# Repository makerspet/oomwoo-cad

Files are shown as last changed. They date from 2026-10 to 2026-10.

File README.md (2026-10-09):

<div align="center">

# OOMWOO One CAD

*Open-source robot vacuum you build yourself.*

3D CAD · STEP · 3D printable · Chassis · Mounts · Open hardware





</div>

DIY build instructions [will be posted here](https://makerspet.com/blog/oomwoo-vacuum-build-instructions/). Please visit project home [OOMWOO](https://github.com/makerspet/oomwoo).

## Repository layout

- [`designs/`](designs) - product designs: one folder per product, one subfolder per variant ([how it is organized](designs/README.md)). [`designs/one/stock/`](designs/one/stock) is the OOMWOO One itself.
- [`lib/`](lib) - off-the-shelf parts, 3D scanned or sourced as STEP
- [`docs/`](docs) - spec and design references

## Active work in progress

oomwoo_base_sept_7

side_brush_reverse_engineered

vacuum_assembly_reverse_engineered

## Dock concept

oomwoo_dock_concept

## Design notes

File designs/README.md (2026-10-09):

# Designs

One folder per product, and inside it one folder per variant.

```
designs/
  one/              OOMWOO One robot vacuum
    stock/          the standard OOMWOO One: Fusion 360 sources, STEP exports
    agentic/        AI-generated design experiments, kept for reference - not the design
```

## Why variants

A mod rarely touches one part. A top plate that gives a cat a ride, say, changes the
enclosure, the bumper and the way they mount to the base. A variant folder holds the
**whole** modified design, so anyone can open it and build it in one go instead of
piecing changed parts together from several places.

## Adding a variant

1. Copy `stock/` (or the variant you are starting from) to a new folder named after
   your mod, for example `designs/one/cat-rider/`.
2. Change what you need.
3. Add a `README.md` saying what changed and why, with a picture if you have one.
4. Open a pull request.

Off-the-shelf parts - motors, sensors, brushes, the 3D-scanned STEP models - live in
[`lib/`](../lib), shared by every product and variant.

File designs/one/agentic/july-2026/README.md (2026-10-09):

# Agentic CAD experiment (July 2026)

An early experiment for OOMWOO One: we tried an agentic CAD pipeline to see how far it could get. An LLM-driven multi-agent workflow was asked to turn the project spec and a set of component STEP files into a complete, closed, 3D-printable robot vacuum, written entirely as code-CAD.

This folder is a snapshot of that experiment, shared as-is in the build-in-public spirit of the project.

> **This is not the OOMWOO One design.** It is unreviewed pipeline output from a single revision ("RV02") and has known design errors, listed below. The actual design work lives in [`designs/one/stock/`](../../stock) and [`lib/`](../../../../lib).

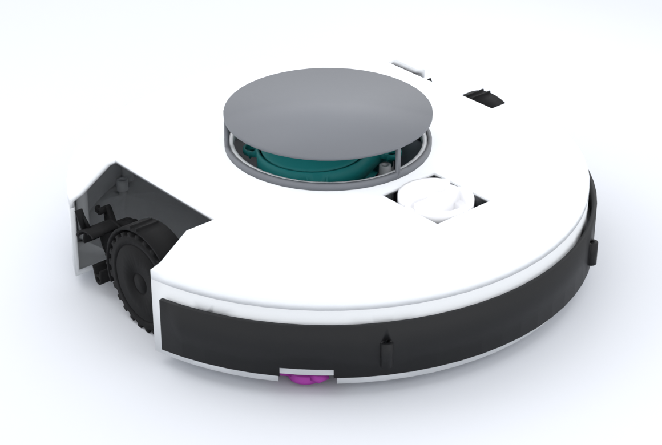
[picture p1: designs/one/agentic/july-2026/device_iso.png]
RV02 closed device, as rendered by the pipeline


## Contents

| File | What it is |
|---|---|
| [`OOMWOO_Device_RV02_Report.pdf`](OOMWOO_Device_RV02_Report.pdf) | 9-page report written by the pipeline: layout, enclosure, verification numbers, print and assembly notes, limitations |
| [`device_full.step`](device_full.step) | Full assembly of that revision: 15 placed components plus the generated base, cover, LiDAR turret cap, bumper, dustbin and battery door (15.6 MB) |
| `device_iso.png` | Render of the closed device, taken from the report |
| `device_full.png` | The same revision with the cover off, showing the component packing |

## How it was made

- **Tooling:** [Claude Code](https://claude.com/claude-code) with Claude Fable 5 orchestrating a multi-agent loop: a designer agent wrote the geometry, and a separate QA agent re-measured the built solids before each phase was accepted.
- **CAD kernel:** [build123d](https://github.com/gumyr/build123d) 0.10.0 on OpenCascade. All geometry is Python code; no GUI CAD was used.
- **Inputs:** the project spec, the LiDAR and compute-module STEP files from [`lib/`](../../../../lib), and stand-in geometry from an older robot vacuum for the parts that had not been 3D-scanned yet.
- **When:** 23-25 July 2026. `device_full.step` is the direct pipeline export of 24 July; nothing in it was edited by hand.

## What worked

- Importing real component STEP files into one coordinate frame and packing 15 of them inside a Ø355 mm envelope with zero boolean interference.
- Generating a base, domed cover, turret cap and front bumper around those components, with numeric gates (interference, clearances, parting-line gap, bumper travel, overall height) checked on the final solids rather than on the generator's intent.
- Swapping one component for another (for example one LiDAR for a different model) with a one-line registry change and regenerating the chassis around it.
- Producing the report, sections and renders automatically from the same model.

## What did not

Every gate the pipeline set for itself passed, and the report says so. What it had no gate for was design intent: which way up a part goes, and whether the layout makes sense as a robot vacuum. Human review of this revision found:

- Side brush mounted sideways and upside down; caster wheel upside down; rubber push-button cover upside down.
- LiDAR puck off-centre, inside an oversized turret.
- Suction fan on the opposite side of the robot from the main brush.
- A round port in the floor with no airflow path designed around it.
- Bumper attached outside the cylindrical body, with its mounts exposed on the exterior.
- Battery-compartment door smaller than the battery, and the battery itself a stand-in rather than the Roborock pack in the BOM.
- No mop.

The takeaway at the time: the pipeline was dependable at what can be measured (fit, clearance, interference, print-bed limits) and unreliable at what has to be understood (orientation, function, layout). Output like this needs a person to review it before it is treated as a design.

## Credits and license

Experiment by Muhammed Ikbal Arikan ([@mikbalarikan](https://github.com/mikbalarikan)) as part of the OOMWOO One CAD work. Released under the repository's [Apache-2.0 license](../../../../LICENSE).

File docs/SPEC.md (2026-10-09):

OOMWOO One open-source vacuum robot spec

A brain-dump with some explanations. First of all, there are 3 living documents

- BOM.md https://github.com/makerspet/oomwoo/blob/main/BOM.md
- Companion article https://makerspet.com/blog/how-to-source-bom-for-oomwoo-open-source-vacuum-robot/
- 3D design spec https://github.com/makerspet/oomwoo-one-cad/blob/main/docs/SPEC.md

All 3D CAD design files live in this repo https://github.com/makerspet/oomwoo-one-cad

Let me go over each component and explain the thinking about it. Please let me know any comments/questions.

I will list the "recommended selection" as well as "backup alternatives".

- "Drive wheel assembly pair". Recommended - reuse Roborock S5 Max wheels because they are abundant in the aftermarket https://makerspet.com/blog/how-to-source-bom-for-oomwoo-open-source-vacuum-robot/#driving-wheels There is a backup alternative - Roborock S5 (non-Max) wheels. These are also abundant, but older. So, don't use those, lets stick with Roborock S5 Max.
- "Caster wheel". Recommended - caster wheel off iRobot Roomba I3/4/6/8, J7/Plus J7 E5/6 500 600 700 800 900 series. It appears to be the most abundant in the aftermarket. iRobot has used the same caster part using in all those models over years. Backup alternatives - plenty available off-the-shelf on AliExpress; or 3D print using TPU.
- "Suction fan". Recommended - BL24131616 10kPa. Recommended for 2nd vacuum version - 36 kPa from Roborock Saros 20, . Backup alternatives - fans with lower suction. Why 10kPa - modern vacuums use increasingly stronger suction. Old vacuums use mere 2-2.5kPa. Users want to see bigger kPa suction.
- "Main brush". Recommended - "Anti-tangle split single roller, rubber and bristles" for Roborock Saros. Users *strongly* want no tangling at all. This roller type seems one of the best - but *I may be wrong*. Another roller that appears to be great is "Anti-tangle hair-cutting dual roller, rubber and bristles", sold as replacement for Dreame vacuums. Please read about roller choices here https://makerspet.com/blog/how-to-source-bom-for-oomwoo-open-source-vacuum-robot/#main-brush Another option is 2 rollers, but having 2 rollers (I assume) will complicate your CAD design. So single (or single split?) roller seems best for 1st vacuum version. The 1st vacuum version's name is OOMWOO One.
- "Battery pack + BMS". Required - the standard Roborock battery. Roborock has been using it over many years and many models. It comes with built-in protection and thermistor. No obvious alternatives.
- "2D LiDAR". Recommended - "PCB mark X-WPFTB-V2.6.2, possibly Camsense". However, there are many alternatives. Some users own different LiDARs - and want to reuse them. So, we should let users pick their LiDAR - by 3D printing a custom mounting bracket.
- "Compute Module". Required - Raspberry Pi CM4 or CM5. CM4 and CM5 have identical dimensions.
- "I/O board". Required - custom-designed PCB https://github.com/makerspet/oomwoo-io-board. The I/O board will have all motor/sensor connectors, driver ICs. The "Compute Module" will plug into the I/O board. The I/O board shape/dimensions is *not* set - it will be decided based on your CAD design.
- "Cliff sensors". Required - "cliff sensor + bumper switches bundle" iRobot Roomba 500 600 700 800 528 552 564 595 560 570 610 615 620 625 630 650 off-the-shelf, abundant in the aftermarket. The "bundle" includes 4 IR cliff sensors and 2 bumper switch assemblies. Backup alternatives - if this bundle doesn't work for you, let me know, I will suggest alternatives. Please note - some vacuums have 4 IR cliff sensors, while others have 6. The typical 4-sensor placement is (1) around the caster wheel (in the front) and in front of each driving wheel. 6-sensor vacuums add one sensor just behind each driving wheel. I've noticed some vacuums have 5 sensors (only one driving wheel has 2 cliff sensors). Generally, I'd like to have 6 cliff sensors, but 6-sensor bundles are harder to find/purchase.
- "Bumper switches". Required - please use the iRobot bundle. If you find a problem using these - let me know.
- "Main brush motor, gearbox". Required - let's use one off Roborock S5 because it is abundant. However, this assembly fits Roborock brushes with bristles (which tangle hair badly). So, you may need to design some sort of adapter to accommodate tangle-free brushes. Backup alternatives - we can buy the DC motor and 3D print gears using an SLA resin printer. But I'd like to avoid this additional complexity if possible. FYI, commercial vacuums use RS390 and RS395 DC motors.
- "Side brush". Recommended - "2-arm curved" side brush from Roborock Saros. It seems better at anti-tangling (but I haven't checked). Backup alternatives - older Roborock side brushes or Dreame side brushes.
- "Side brush motor". Recommended - only one side brush, extendable, from Roborock Qrevo https://www.alibaba.com/product-detail/Roborock-Telescopic-Robotic-Arm-Side-Brush_1601598853246.html Backup alternatives - if the recommended one doesn't work for you, let me know, I will check Dreame X40 and Dreame X50 extendable side brush assemblies.
- "Wall sensor". Required - two little custom-designed PCB (one left, one right). These sensors (1) detect IR signal from the dock (2) detect wall (in a crude way). Backup alternative - a Roborock wall sensor assembly is available on AliExpress, but not abundant.
- "Dock homing sensor". Required - a little custom-designed PCB with two IR sensors, in vacuum rear front. Backup alternatives - let me know if there is a problem and I will check.
- "Carpet sensor". Required - ultrasonic 300kHz material sensor, fixed 30mm distance above floor. This model for your initial CAD design https://www.aliexpress.us/item/3256808845934210.html and this model for volume https://htwsensor.en.made-in-china.com/product/jARpDPKoaxVz/China-300kHz-Carpet-Material-Recognition-Sensor-for-Robotic-Vacuum-Cleaner-Ultraosinc-Sensor-Transducer.h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 .
- "Charging contacts" (on the robot). Recommended - DIY using a nickel-plated steel strip (purchased on AliExpress). Located in the robot's rear around the homing IR sensor PCB. No springs. Strip width/length - up to you. AliExpress has 10-12mm. Each contact (positive, ground) connects to a PCB connector cable. The contact-to-wire connection could be accomplished by designing a tiny 3D printed "terminal'. Have a machine screw pressing the (stripped) wire against the strip.
- "Mop motor assembly". Recommended - 2 rotary/disk mops. One static, one extendable. Use Roborock Qrevo FlexiArm https://www.alibaba.com/product-detail/Mop-Deceleration-Motor-Retractable-Mopping-Module_1601599652498.html Backup alternatives - if the Roborock Qrevo doesn't work for you, I can search Chinese ODM making Dreame MopExtend.
- "Obstacle avoidance camera". Recommended - 1x front-facing OV5647 with a 16-pin flexible cable, ~130 degree FOV. Backup alternatives - none that are cheap.
- Bagless vs bag dock. Recommendation: bagless. Why? Multiple users requested bagless; no-one asked for bags. Also, no consumable bag purchase/cost. The dock's dust bin can be 3D printed. However, bagged is easier to engineer. Bagless needs reliable separation (a working cyclone + washable filter). Designing a good cyclone is important. A poor one sends fine dust straight to the filter, clogs the filter, and suction dies.
Auto-empty design. Recommendation: bottom extraction (Roborock style). Why? This is what my Claude says:
- side brush with extensible arm assembly - expensive, hard to find retail. Roborock uses lots of gears; the brush DC motor both actuates the brush and the arm. Design from scratch using a little timing belt, aluminum timing pulleys and a geared DC motor (metal gearbox comes with the motor). 3D-print the assembly enclosure This avoids having to 3D print gears and keeps the build inexpensive.

=== Claude =====================================

1. Gravity is on your side. Dust settles to the bottom of the bin, and bottom extraction pulls it downward into the dock bin. A dedicated side/rear vent higher on the bin fights gravity — you're asking the fan to lift settled dust before it can carry it out.
2. Simplest robot-side port: one flap. You add a single spring/gravity trap door on the bin bottom — no second sealed opening in the bin. A dedicated vent means a second aperture you must seal against leaks during every vacuuming run.
3. Flat, forgiving dock mating. The dock side is just a gasketed hole in the base plate; the robot parks over it. Flat-plate-to-flat-plate tolerates alignment error far better than threading a nozzle into a port (which a dedicated vent requires). Your ramp/alcove already gets the robot "close enough," and a broad base port forgives the rest — same philosophy as oversizing the charging pads.
4. Proven and measurable. It's the dominant industry design, so you can study/measure a real Roborock dock to de-risk the printed geometry.
5. It decouples from your crowded rear. Your rear is already busy — vertical contacts + mop wash tray (back-in docking). Putting auto-empty on the underside keeps it spatially separate from that cluster.

The hard part is the same for both: the valve + the airflow path

Whichever port you choose, the real engineering is the flap valve and the makeup-air path, not the port location:

- The flap must do two contradictory things: seal tightly during vacuuming (so the robot's own fan doesn't lose suction through the auto-empty port) yet open freely under the dock's airflow. Bottom extraction makes this natural — the dock's downward suction pulls an inward/downward flap open, and spring + gravity reseat it. A high side/rear port needs a more deliberate valve.
- You must give the emptying airflow a makeup-air inlet, or the dock fan just pulls a vacuum against a sealed bin and moves nothing. The clean trick (and what Roborock does): let the dock's suction draw makeup air in through the robot's own intake mouth — which is right there at the bottom — so air sweeps through the bin and out the bottom port, entraining settled dust on the way. Design the bin so that emptying airflow traverses the whole bin volume rather than short-circuiting between two nearby openings. This is the single thing that determines whether auto-empty actually evacuates dust vs. just whistling.

Why not the dedicated bin vent

- Its only real advantage is a seal that's higher and away from floor-level dust. That's outweighed by: a second aperture to seal, a nozzle-to-port mating that's alignment-fussy, fighting gravity, and more total seals — all worse for a printed part where every seam is a potential leak. Not worth it.

Two build-specific notes

- Bagless synergy: bottom extraction drops dust straight down into the dock's printed bin sitting in the base — exactly what you want for the bagless, printed-container design you chose. Gravity does half the work of separating debris before the dock cyclone/filter even acts.
- Since the robot backs in rear-first (mop-dock orientation), position the dock base's suction hole under wherever the robot's bottom bin-port ends up in the docked position — likely forward of the mop/contact cluster. This is part of the same frozen dock interface as the contacts and the beacon, across all three tiers.

So: pull from underneath through a single bottom trap-door, let makeup air come in via the robot's intake so the flow sweeps the bin, and drop it into the printed dock bin by gravity. The dedicated-vent approach adds sealing complexity for a benefit you don't need.

Following modern (2026) consumer mop robot design, OOMWOO One requires

- one right front side brush (not two), with an extendable arm (swings out to the side to clean under cabinets)
- mop is 2-disk rotary (not roller for now); the right mop is extendable (swings out to the side to clean under cabinets); the left mop is fixed
- mop disks land into the dock tray (for mop washing, drying)
- having charging contacts on the *rear vertical face*
  - charging contacts cannot be on the robot's underside because this is where the mop wash tray sits
- vacuum *backing* into the (wash) dock (not driving in front-first)
- robot's dock homing sensor must be on the *rear vertical face* between the charging contacts
- robot's charging contacts are "dumb" (not spring-loaded), use an nickel-plated steel strip
  - nickel-plated steel strips resist corrosion, scratching
- charging contacts on the dock have to be spring loaded, with gold-plated pogo pins, 4A 20.1V to provide 65W
- TODO bagless or not
- LiDAR must be inset 10+cm from vacuum's enclosure edges
  - because LiDAR sensor has a ~10cm dead zone around it
- place LiDAR slightly off-vacuum-center
  - this allows capturing scans from new viewpoints while vacuum spins in-place without getting stuck (usually when lost to regain its whereabouts on the map)
- need to lift mops (when traveling over carpet) 12mm
- need a [carpet sensor](https://makerspet.com/blog/how-to-source-bom-for-oomwoo-open-source-vacuum-robot/#carpet-sensor) (ultrasonic ~300kHz) placed in front of main brush; carpet detect causes mops to lift, stop spinning, main brush to spin appropriately for carpet
  - carpet sensor detects carpet ahead of time as the vacuum travels forward, so the mop is always lifted over carpet
- need 2 side wall sensors (left, right)
  - wall sensors detect dock presence (by receiving IR signal from the dock) and act as a crude wall following (intensity based) sensor
  - wall sensor has to be a small custom PCB
- drving wheels should be centered, wide apart
  - let's try reusing [Roborock S5 Max assembly](https://makerspet.com/blog/how-to-source-bom-for-oomwoo-open-source-vacuum-robot/#driving-wheels) because it is abundant in the aftermarket
  - each wheel comes with a wheel drop sensor (a microswitch)
  - FYI some vacuums don't center driving wheels exactly
- robot-to-floor gap is largely defined by the drive wheels
- caster wheel - front center
  - let's try reusing the abundant [iRobot Roomba](https://makerspet.com/blog/how-to-source-bom-for-oomwoo-open-source-vacuum-robot/#caster-wheel)
- I/O board and compute module - front center top, shape TBD
  - board has pushbuttons
- battery pack - reuse abundant standard [Roborock battery pack](https://makerspet.com/blog/how-to-source-bom-for-oomwoo-open-source-vacuum-robot/#battery-pack)
  - place battery pack on the vacuum bottom, with an access door with screws, roughly under the I/O board or slightly behind, roughly centered to equalize pressure on both wheels and mops
  - TODO check if battery should be close to mops for cleaning pressure

## Dock

### Specs

- ~use an external certified 24 V DC brick (200–350 W)~
  - the dock only sees 24V?
  - inherit the brick's UL/CE certification?
  - ~reuse 25.2 V stick-vac motors, e.g. Dreame M10-E-4 (25.2 V, 310 W) handheld motor, use for auto-empty~
- power 1600W, see [X20 dock teardown](dock_teardown_x20.pdf)
- ~dock contains USB PD sink, converts power to 20-24V charger contacts~
  - dock charger contacts check for robot's presence (resistance), enable power only when robot is present
- skip hot air dry, use a regular fan
  - Hot air dries the mop in ~2–3 h instead of ~6. But the robot sits docked for hours anyway.
  - Dropping the heater removes your biggest power draw and biggest thermal-safety risk.
- bagless
  - No consumable lock-in. The bin is a printed part.
  - Downside: emptying a dusty bin by hand. The dock bin is far larger than the robot's, so you empty it ~monthly instead of every run. Design a wide opening + lid to limit the dust puff.
  - Bagged is significantly easier to engineer — the bag is the container and the filter, so there's no cyclone to design.
  - Bagless needs real separation (a working cyclone + washable filter), and the cyclone is the main engineering risk of this choice — a poor one sends fines straight to the filter, it clogs, and suction dies.
  - Maybe prototype the auto-empty tier bagged to de-risk the port/sealing/motor work, then move to bagless once you've validated a cyclone geometry. Ship bagless.
- bottom extraction auto-empty
  - why? proven, Roborock style; gravity helps dust fall/evacuate vs non-bagless rise; only one, simple robot-side port, one flap - no sealed opening in the robot's dust bin needed; robot-to-dock flat plate-to-plate gasketed mating is relatively simple vs bagged nozzle-into-the-port mating; frees us space in the robot's rear
- tubing, see [X20 dock teardown](dock_teardown_x20.pdf)
  - water 9mm OD clean, 11mm OD dirty, clean mop spray 6mm OD
  - air auto-empty ID 29mm OD 33mm
- canister present sensors: 2x (clear + dirty water canisters): magnet embedded into canister, hidden hall, see [X20 dock teardown](dock_teardown_x20.pdf)
- water level sensors
  - clear water tank : floaters magnet/hall
- TBD sensors
  - TBD dock-side IR turbidity sensor
  - TBD thermistor + independent thermal fuse
  - TBD dock base leak/flood sensor
- TODO cleaning solution
- TBD hot water mop wash
- TBD hot air mop dry
- safety
  - Mains stays outside (certified brick)?
  - Physically separate wet section from electronics; drip loops, drainage, a dam/lip toward the contacts.
  - Presence-detect the robot, energize charge contacts only when the robot is docked
  - If using heater: redundant thermal cutoff (thermistor + independent thermal fuse), never fan-less.
  - Document as advanced build.

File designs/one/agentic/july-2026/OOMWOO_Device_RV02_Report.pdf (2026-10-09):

# OOMWOO One

## Full Closed Consumer Device — RV02 Report

From agentic-pipeline proof-of-concept to a sealed robot-vacuum: expanded component registry, a fully enclosing cover + turret cap, a functional-ready front bumper, and true bottom-extraction — every full-device gate verified on the built solids.

Prepared for | Ilia
Engagement | Upwork Milestone 2 — “Detailed 3D modeling for the chassis”
Scope of RV02 | Client-directed expansion of the POC into a complete closed device (§8)
Companion | OOMWOO_Chassis_POC_Report.pdf (the pipeline proof-of-concept; unchanged)
Toolchain | build123d 0.10.0 / OpenCascade (OCP) booleans; multi-agent design + QA loop
Status | Phase 5B APPROVED — all full-device gates pass
Date | 2026-07-25

What RV02 adds — and what remains a placeholder.
The proof-of-concept proved the pipeline: import real component STEPs, pack them in one coordinate frame, auto-generate a printable chassis, gate it numerically, and hot-swap a component with a one-line change. RV02, at the client’s direction, closes that open chassis into a coherent consumer product — a low-profile domed cover with a removable LiDAR turret cap, a functional-ready front bumper, a side-brush pair, a UI button cluster, a custom I/O board and a custom bottom-extraction dustbin. The functional components are still dimensioned placeholders (repo LiDAR/CM4 + the reverse-engineered A8S library) awaiting 3D scans; the swap protocol means each scan drops in as a one-line registry edit. All numbers below were re-measured on the built solids by an independent QA agent; the designer agent’s claims were not trusted.

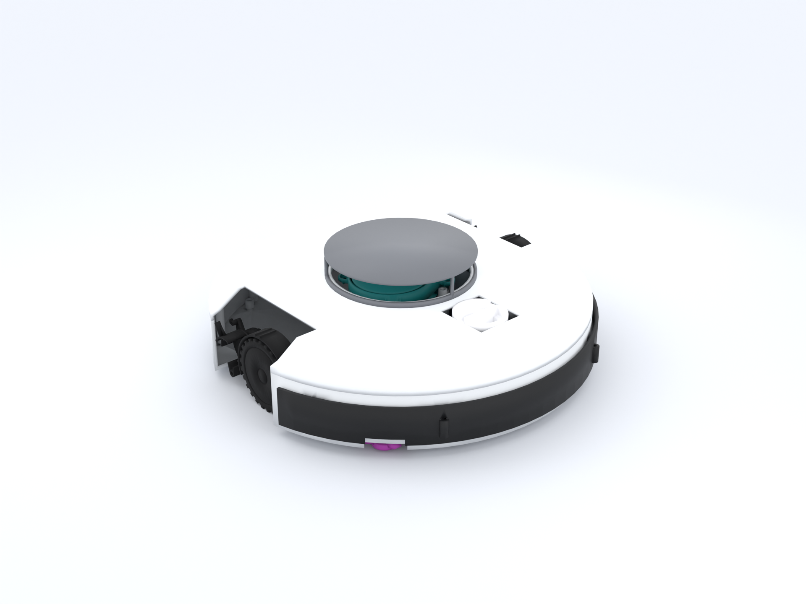
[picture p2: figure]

The closed RV02 device — domed cover, removable LiDAR turret cap, recessed UI button, wrap-around front bumper, exposed drive wheel and front-corner side brush.

## O. — makerspet / OOMWOO (makerspet/oomwoo-one-cad, Apache-2.0)

OOMWOO One — Full Closed Device (RV02) | Upwork Milestone 2

## 1. Executive summary

RV02 takes the approved proof-of-concept chassis and, per DESIGN_SPEC.md §8, expands it into a complete closed consumer robot vacuum. The ten POC components did not move; five new functional elements were added, the base was amended for true bottom-extraction and for the new enclosure interfaces, and a threepart outer shell (cover, turret cap, bumper) was designed and verified around the whole assembly. The device now reads as a finished product and passes every acceptance gate in §8.5.

(a) Expanded registry (10 → 15 components): added a side-brush + its motor, a UI button cluster, a custom I/O board and a custom thin-wall dustbin — all placed without interference against the existing ten.
(b) Fan relocation for true bottom extraction (client decision): the suction fan was moved rear-left so the dustbin can seat on the base floor and route a Ø52 mm extraction port through the floor within the mop-exempt bin footprint.
(c) Enclosure: a full-Ø355 low-profile domed cover (parting line at the base rim, Z=60), a removable LiDAR turret cap with a 360°-clear sensor window, and a functional-ready 150° front bumper with travel, spring seats and guide followers.
(d) Full-device verification: cover clears all 15 components (0 mm³
), seats on the base at a ∼0.04 mm parting gap, the bumper sweeps clean to a hard-stop, and the closed device stands 108 mm tall inside the height budget.

Headline result.
The closed device is verified. Cover ∩ every one of the 15 components = 0, cover ∩ base = 0 with an ∼0.04 mm parting gap, turret cap slip-fits at 0.30 mm over a 360°-clear sensor window, the front bumper travels its full stroke to an intended tangent hard-stop with zero clash to cover or side-brush sweep, and the recessed UI button sits ∼1.5 mm proud. Total device height is 108 mm (≤115 budget); device diameter is Ø355 mm bare, Ø367 mm across the bumper. Every printed part has a stated print orientation and split. QA verdict: Phase 5B APPROVED, no blocker or major findings.

Closed device at a glance

Parameter | Basis | Value
Device height (incl. turret cap) | Measured on the assembled solid; bud- get ≤115 | 108.00 mm
Device diameter | Bare cover / across front bumper | Ø355 / Ø367 mm
Base (chassis) volume | Final, after side-brush motor-boss fix | 481,399 mm³
Cover / bumper / cap volume | Three printed shell parts | 228,018 / 51,607 / 44,754 mm³
Cover ∩ 15 components | Boolean common volume, all parts | 0 mm³
Parting-line gap (cover↔base) | Re-measured at 4 angles, Z=60 | ∼0.04 mm
Bumper travel (rest → hard-stop) | 150° arc, sweep-verified | 2.86 mm → 0
Dustbin capacity (thin-wall, 1.2 mm) | Custom bottom-extraction bin | ≈0.189 L
Fasteners (heat-set / screw / align) | Full base + enclosure inventory | 48 features

## 2. What’s new in RV02

### 2.1 Expanded component registry (10 → 15)

The registry-driven pipeline made the expansion additive: five new entries were placed and gated against the existing ten with a single 15-solid interference pass (0 clashes). The custom parts (I/O board, dustbin) are parametric — their single source of truth is custom_parts.py.

Prepared for Ilia O. • makerspet / oomwoo-one | 1

New component | Source | Placement / key numbers (measured)
side_brush | A8S-U04 (placeholder) | Front-right corner (116, 116); swept radius 20.84 mm, floor clearance 1.50 mm, edge overhang 7.39 mm (≤10)
side_brush_motor | A8S-M06 (placeholder) | Inboard at (105, 78) driving the corner disc via an implied arm / Ø8 pass- through (flagged — see §7)
ui_button | A8S-E04-01 (placeholder) | Front-center (0, 105); lowered to sit ∼1.5 mm proud of the cover; cutout from measured bbox +0.4 mm
io_board | custom parametric plate | 54.2×39.2×1.6 mm on the compute deck, connector edge −Y (rear-accessible)
dustbin | custom parametric bin | 57×56×66 mm thin-wall (1.2 mm), ≈0.189 L, Ø52 bottom port, removable from top

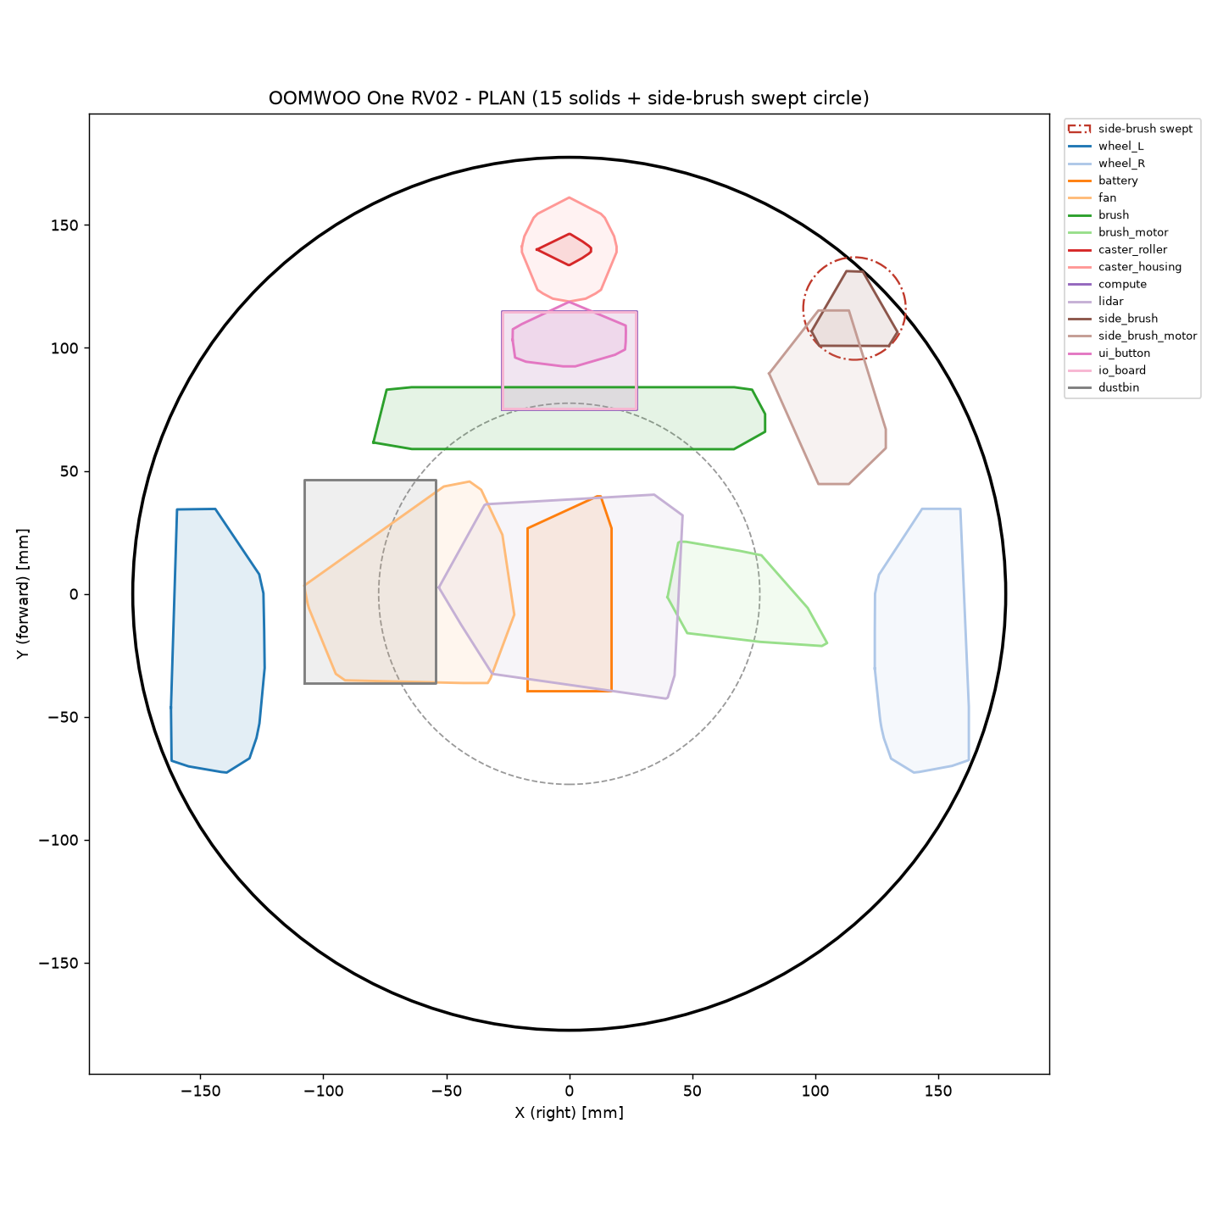
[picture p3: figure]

Figure 1. RV02 expanded plan — all 15 solids packed inside the Ø355 mm envelope, including the new front-right side brush (with its dash-dot swept circle), the front-center UI button, the custom I/O board and dustbin. The ten POC components are unchanged.

### 2.2 Fan relocation for true bottom extraction (client decision)

In the POC the suction fan and dust-bin bay were a single reserved open volume at front-left. To realize the spec’s bagless, bottom-extraction auto-empty (§2/§8.1), the client directed that the fan be relocated so the bin can reach the base floor. The fan was moved rear-left (registry position (−65, −52); measured bbox Y [−93.3, −10.7]); the fan-bay pocket, being derived from the measured bbox, tracked the move automatically. The dustbin then dropped onto the base floor (Z[12, 78]) directly above a Ø52 mm extraction port cut through the floor, ringed by a 1 mm-recessed, 4 mm-wide sealing land. Port-to-bin concentricity and bin floor-seat both measure 0.00 mm; the dustbin-to-fan gap after the move is 1.20 mm.

### 2.3 Base amendments (Phase 5A)

Every previously approved feature and placement was retained; the base gained only additive features, and one bugfix took its final volume to 481,399 mm³
:
- Side-brush motor-boss bugfix (_SBM[3]→_SBM[4]) — corrected the boss index; this is the source of

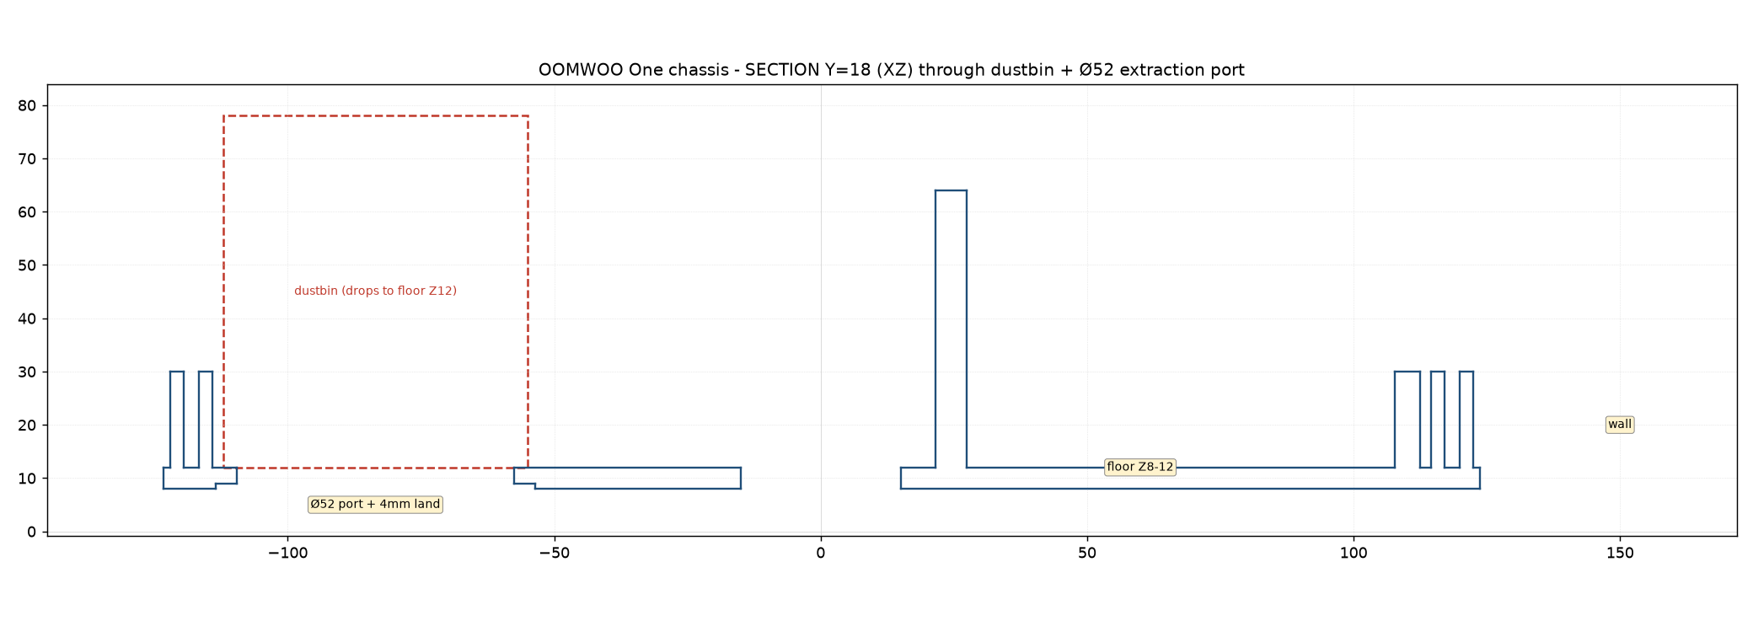
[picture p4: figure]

Figure 2. Base amendment — XZ section at Y =18 through the dustbin and the Ø52 mm bottom extraction port. The thin-wall bin drops to the floor (Z=12); the port pierces the base floor (Z 8–12) with a recessed sealing land. Framed with margin, no clipping.

the base-volume change from the POC baseline.

- Side-brush recess Ø43.7 at (116, 116), edge-open, with 1.00 mm disc-to-pocket clearance; motor gets 2 M3 bosses at (76, 44) / (76, 112) plus a Ø8 drive-arm pass-through.
- Bottom-extraction port + sealing land (above) within the mop-exempt bin footprint.
- Bumper interface on the front inner wall — 2 spring bosses (±86, 149), 2 guide slots (±155.9, 72.7), and 4 front-wall pass-through windows for the bumper followers.
- Cover interface — 8 M3 cover-mount bosses (screw-from-below through-holes) + 2 alignment blind-holes.

## 3. Enclosure: cover, turret cap & bumper

### 3.1 Top cover

A single full-Ø355 mm low-profile domed shell closes the device, with the parting line at the base rim (Z=60) and a smooth consumer top that exposes nothing but the LiDAR turret and the UI button. Measured shell walls are 2.45 mm (skirt and dome) and 3.00 mm at the turret collar — all ≥2.0 mm. The cover fastens to the base with 8 M3 heat-set bosses, screwed from below through the base, and locates on 2 alignment pins seating in base blind-holes; it also carries the LiDAR turret opening + collar, the UI-button cutout with two support brackets, and two wheel-well arch cutouts.

### 3.2 LiDAR turret + removable cap

The turret collar (inner/outer radius 64.5 / 67.5 mm, top Z=87.0) rises from the measured LiDAR footprint, and a removable printed cap slips over it with a 0.30 mm fit (cap inner radius 67.80 vs collar 67.50 — within the 0.2–0.4 mm target). The cap roof sits at Z 105.5–108.0; the sensor window band (Z 88.5–102.5) is 360° clear — no cover material in the annulus, crossed only by the three standard Ø3.5 mm cap-support legs. All of this regenerates from the measured LiDAR on a scan swap.

### 3.3 Front bumper

The bumper is a printable 150° front-arc shell (inner/outer radius 180.5 / 183.5 mm) carrying two spring seats (±30°), two guide followers (±65°) that pass through the four base wall windows, and a side-brush relief scallop. It rests 2.86 mm off the base (spec target 2–3 mm) and travels rearward to an intended tangent hard-stop against the front wall at −3.0 mm, with the button 1.5 mm proud unaffected. Springs and detents are not modeled (bosses/followers only), consistent with §8.3.

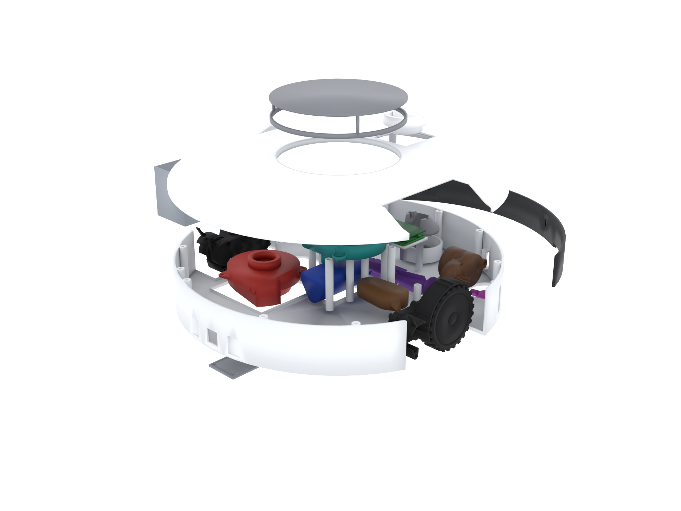
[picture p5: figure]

Figure 3. Exploded view — removable turret cap (top), full-Ø355 domed cover lifting off the base at the Z=60 parting line, and the front bumper separating forward. All internal components remain seated on the base.

The button is consumer-flush.
In Phase 5B the UI button was lowered (registry Z 98.3 → 75.3) so its measured top (85.00 mm) sits 1.52 mm proud of the cover outer surface (83.48 mm) at (0, 105) — a normal button feel. Its cutout ring holds a 0.40 mm gap (bbox +0.4/side) and it clears the nearest part below (the I/O board) by 2.41 mm. The cutout and its two bracket bosses regenerated from the newly placed bbox — measuredriven, not hand-tuned.

## 4. Full-device verification

All values re-measured independently on the built solids (build123d 0.10.0; OCP booleans, SolidClassifier, DistShapeShape). The compute module remains a pinned proxy box (CM4 not imported).

Gate (§8.5) | Measured | Requirement
Part validity (cover / bumper / cap / base) | all valid, 1 solid each | valid solids | PASS
Cover wall (skirt / dome / collar) | 2.45 / 2.45 / 3.00 mm | ≥2.0 mm | PASS
Cover ∩ each of 15 components | 0.0000 mm³ on all 15 | 0 | PASS
Cover ∩ base (intended contacts only) | 0.0000 mm³
| ; 11–12 contact patches | 0 material | PASS
Parting-line gap (4 angles, Z=60) | ∼0.04 mm | ≤0.5 mm | PASS
Per-component cover headroom | ≥2.50 mm (tightest: dustbin) | ≥0.4 mm | PASS
Turret cap slip fit | 0.30 mm | 0.2–0.4 mm | PASS
LiDAR sensor window 360° clear | 0 mm³
| in band (3 cap legs only) | clear | PASS
Bumper rest gap → full-travel | 2.86 → 0.00 mm (tangent hard-stop) | 2–3 mm rest | PASS
Bumper ∩ base / cover / side-brush sweep | 0.0000 mm³
| through full travel | no clash | PASS
UI button proud height / clearance below | 1.52 mm proud / 2.41 mm to I/O board | flush / ≥0.4 | PASS
Dustbin fit / port concentricity | bay gap ≥1.20 mm / 0.00 mm | ≥0.4 / aligned | PASS
Device height / max plan radius | 108.00 mm / 183.50 mm | ≤115 / — | PASS

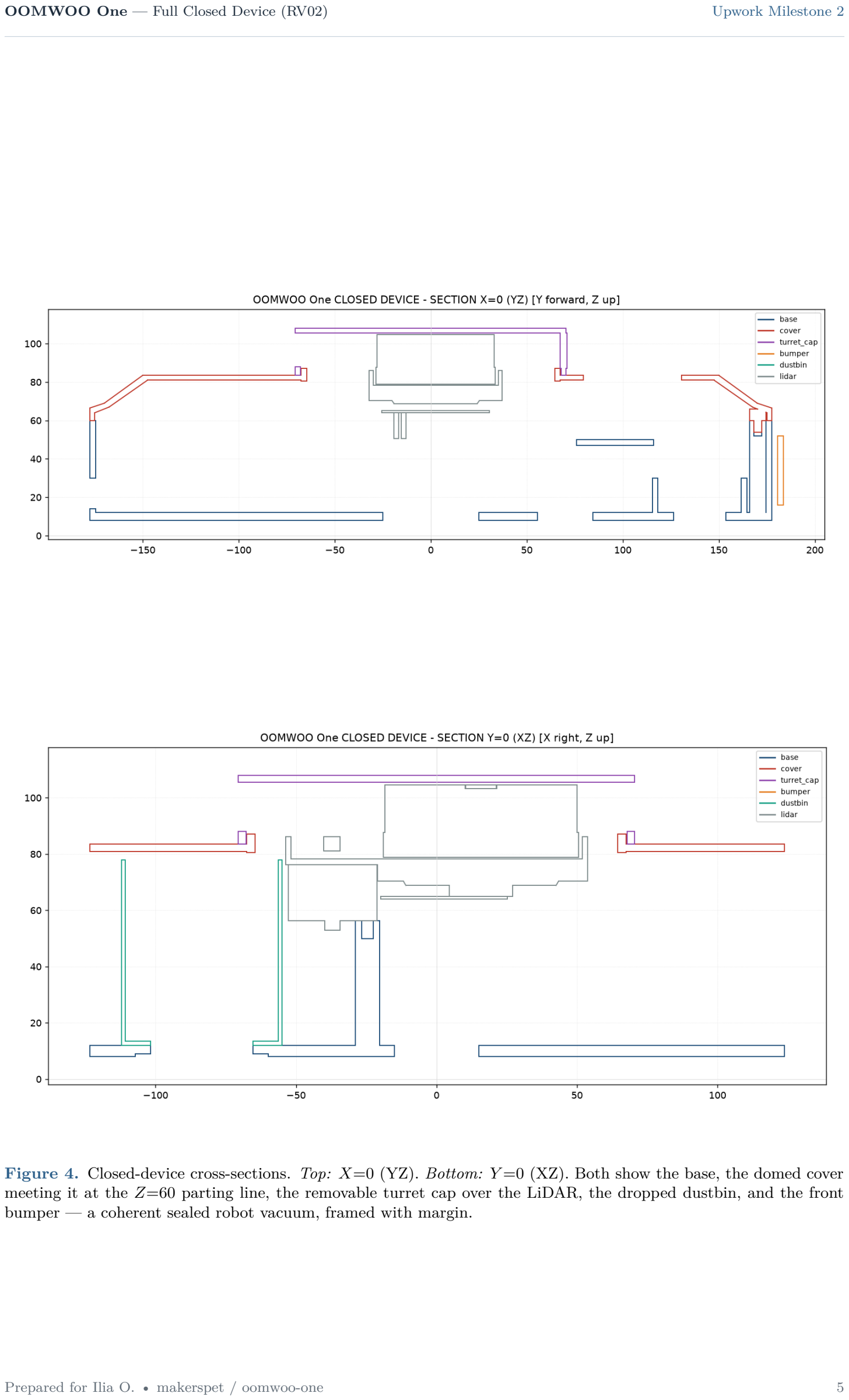
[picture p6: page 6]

Figure 4. Closed-device cross-sections. Top: X=0 (YZ). Bottom: Y =0 (XZ). Both show the base, the domed cover meeting it at the Z=60 parting line, the removable turret cap over the LiDAR, the dropped dustbin, and the front bumper — a coherent sealed robot vacuum, framed with margin.

## 5. Print & assembly

### 5.1 Per-part print orientation & split

Every printed part carries a stated orientation and, where it exceeds the print bed, a split strategy. The cover and base exceed Ø350 and must be split; the cap, dustbin and battery door print in one piece.

Part | Size (mm) | 1-pc fit? | Orientation / split
base | 348×355×64 | no | Floor-down; Ø355>350 → quadrant split at X0&Y 0 (4 D-parts ≈180×180),
| | | dowel + M3 lap joints
cover | 348×355×33 | no | Dome-up; Ø355>350 → half split at X=0 (2 parts ≈355×178), glue/screw rim
| | | seam
turret_cap | 141×141×24 | yes | Roof-up, legs down; fits 256³
bumper | 354×137×36 | no | Arc; split at Y -axis into L/R halves (or print on its back); fits after split
dustbin | 57×56×66 | yes | Open-top-up; walls 1.2 / floor 1.5 / ribs 2.2 mm
battery_door | 38×58×2 | yes | Print flat

### 5.2 Suggested assembly order

1. Print the base quadrants, install heat-set inserts in all bosses, and bond the quadrants (dowels + M3 lap joints) into the full base tub.
2. Seat the functional components on the base: drive wheels, caster, main brush + motor, fan (rear-left), battery, compute + I/O board, LiDAR, side brush + its inboard motor.
3. Drop the dustbin into its floor bay from the top (before the cover) so it registers over the extraction port; fit the battery door plate from underside.
4. Lower the cover onto the base, locating on the 2 alignment pins, and fasten the 8 M3 screws from below through the base into the cover bosses.
5. Press the turret cap onto the collar (0.30 mm slip fit) over the LiDAR.
6. Fit the bumper: engage its guide followers through the four front-wall windows onto the spring bosses (springs/detents added at the functional-prototype stage).

### 5.3 Fastener / mount inventory (48 features)

Feature | Count | Feature | Count
LiDAR seat cradle posts (M3) | 8 | Battery-door bosses | 4
Compute M3 holes | 4 | Door-plate pads | 4
Brush bearing bosses | 2 | Side-brush motor bosses | 2
Brush-motor bosses | 2 | Bumper spring bosses | 2
Wheel-module mounts | 4 | Bumper guide slots | 2
Cliff-sensor bosses | 4 | Cover-mount M3 bosses | 8
| | Cover alignment pins | 2
| | Total heat-set / screw / alignment features | 48

## 6. Assembly views

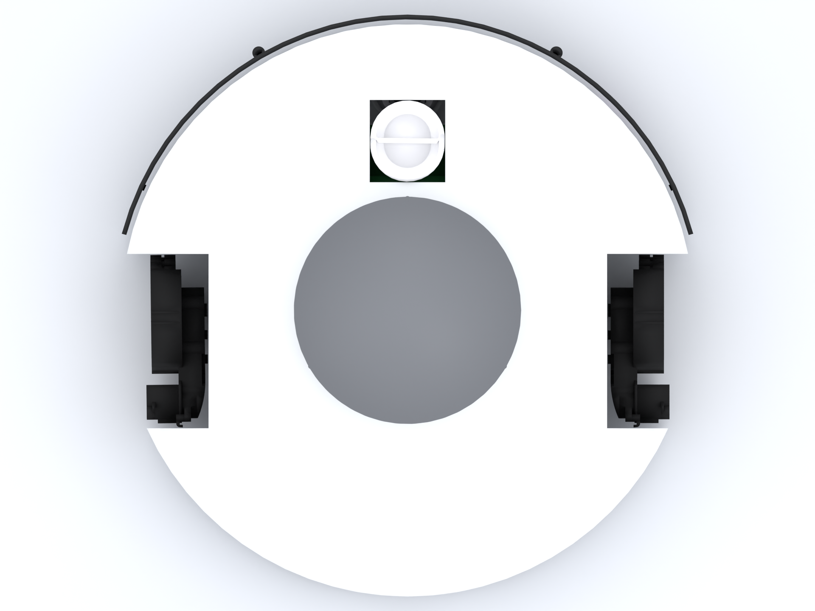
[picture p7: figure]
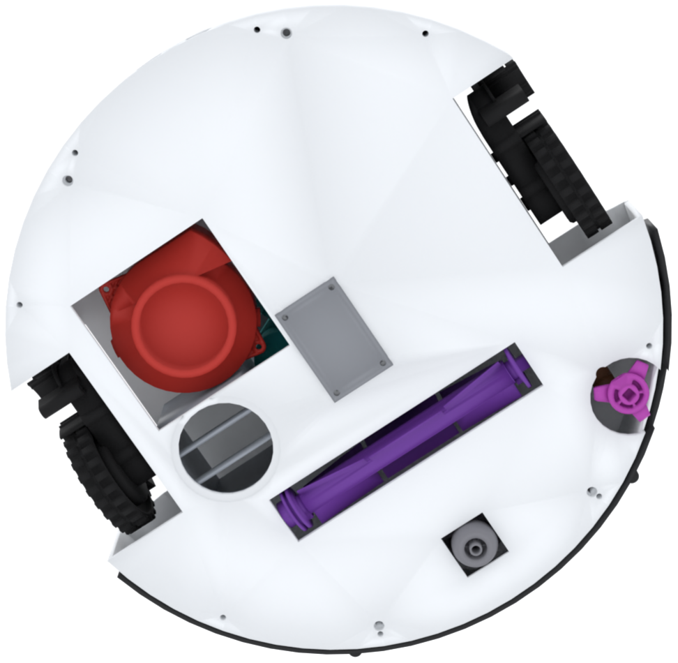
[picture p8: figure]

Figure 5. Left: closed top — domed cover, gray LiDAR turret cap, recessed front UI button, and the wrap-around front bumper with its two wheel-well arch cutouts. Right: underside — relocated fan (red), I/O board plate, main brush (purple), 3-arm side brush (magenta), caster ball, drive wheels and the bottom extraction port.

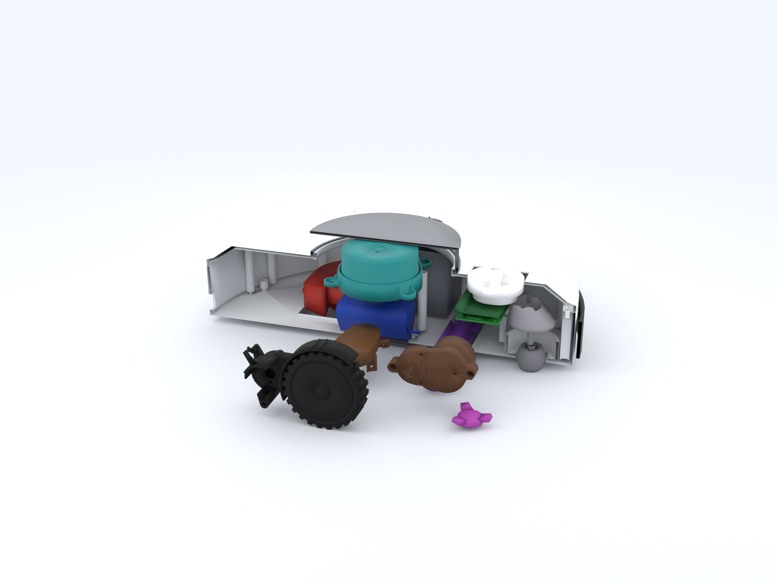
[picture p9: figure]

Figure 6. Cutaway — the sealed device with the cover and turret cap in place, showing the internal packing: LiDAR on its cradle, fan, dustbin, battery, drive train and side-brush corner unit all enclosed beneath the domed top.

## 7. Honest limitations & next steps

RV02 is a complete closed-device model built on placeholder internals; the following are the known limitations and the natural next steps once the 3D scanner arrives.

1. Placeholders pending scans. All functional components remain dimensioned placeholders (repo Li-DAR/CM4 + the reverse-engineered A8S library). The turret collar/cap/window, seat cradle and every pocket derive from the measured placeholder and regenerate on a one-line registry swap — so each scan drops in without a redesign. Fit accuracy improves when the scans land.
2. Bumper springs / detents unmodeled. The bumper carries follower geometry and wall pass-throughs only; the return springs and any retention detent are added at the functional-prototype stage (per §8.3). Full travel is an intended tangent hard-stop on the front wall.
3. Side-brush drive is implied. The placeholder side-brush motor is too large to sit directly above the corner disc without clashing the main brush or exceeding Ø355; it is placed inboard and drives the disc through an implied arm/gearbox (Ø8 pass-through). A real gear-motor selection would firm this up.
4. Dustbin volume is modest (≈0.189 L). The thin-wall bin fits the available floor pocket beside the relocated fan; capacity is limited by the packing. Enlarging it (or trading against runtime between auto-empty cycles) is a layout decision for the next pass.
5. Volute is a later CFD task. The fan bay is a reserved volume; the detailed suction volute/duct is intentionally not designed here and is a downstream, CFD-driven task.
6. CM4 compute is a proxy. The compute module is a pinned proxy box; the real CM4/CM5 STEP swaps in as a one-line registry change when its mount references are needed.

Assumptions to confirm with the client / A8S owner

These carry over from the specification’s open-questions log and gate the transition from placeholders to production intent:

1. A8S → function mapping — the reverse-engineered A8S part identities were proposed by geometry inspection and reconciled against the A8S BOM; please confirm against the physical parts.
2. Overall diameter & height — Ø355 mm / 108 mm is a designer recommendation (diameter is a spec design variable); confirm against your intent. Height is LiDAR-sensitive and drops with a thinner scanned sensor.
3. Compute — CM4 assumed (same footprint as CM5 per the repo); confirm CM4 vs CM5.
4. I/O board outline — modeled as a parametric rectangle with a rear-accessible connector edge per the spec’s “decided by the CAD”; confirm the outline and connector side.
5. Dustbin strategy — ≈0.189 L, top-removable, bottom-extraction port; confirm capacity vs. auto-empty cadence and dock-port geometry.

Recommended next steps

- Scan swap-ins — replace each placeholder via its registry line as scans arrive; re-run the fit loop per component and re-gate.
- Dock interface — design the rear charging-contact + homing geometry and the auto-empty dock mating to the bottom-extraction port.
- DFM pass — draft angles, split-seam alignment/fastening detail, heat-set boss finalization, and a moldability review ahead of tooling.

All numeric values re-measured on the final build123d solids by an independent QA agent (build123d 0.10.0, OCP booleans);

the designer agent’s asserted numbers were not trusted. Companion to OOMWOO_Chassis_POC_Report.pdf. Prepared for Ilia

Prepared for Ilia | 8

O., Upwork Milestone 2, makerspet/oomwoo-one — 2026-07-25.

### O. • makerspet / oomwoo-one

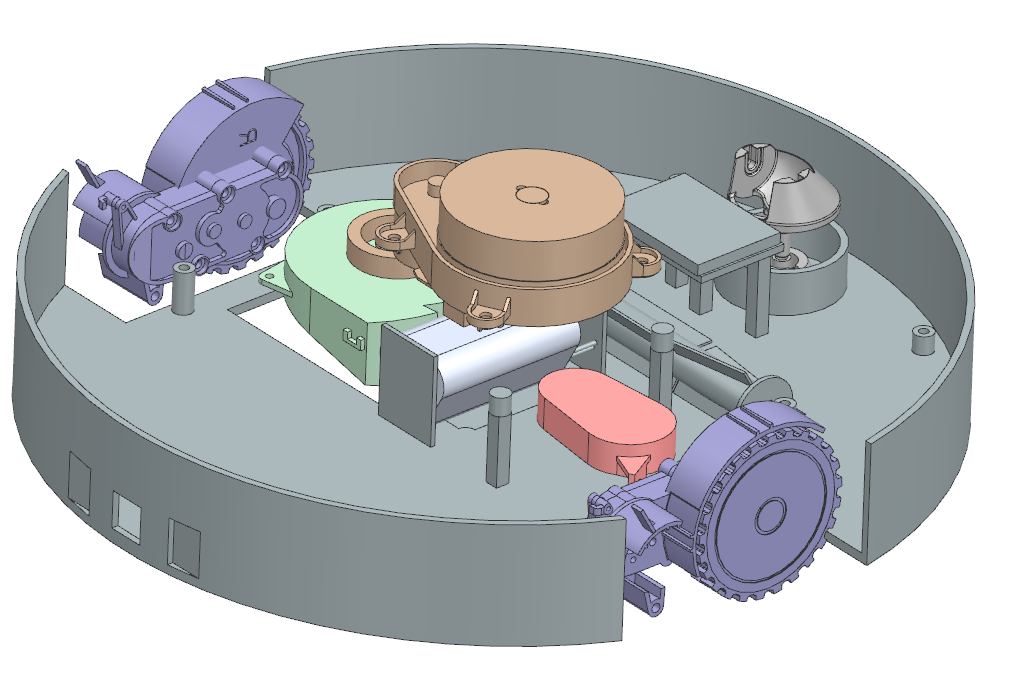
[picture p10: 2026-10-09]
designs/one/agentic/july-2026/device_full.png

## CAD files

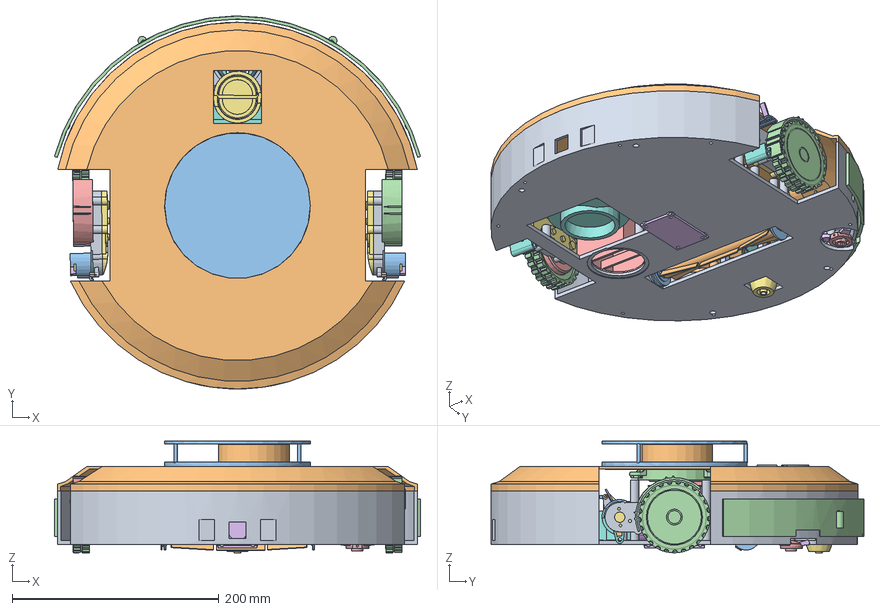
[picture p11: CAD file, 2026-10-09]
designs/one/agentic/july-2026/device_full.step
354.5 x 361.0 x 108.0 mm

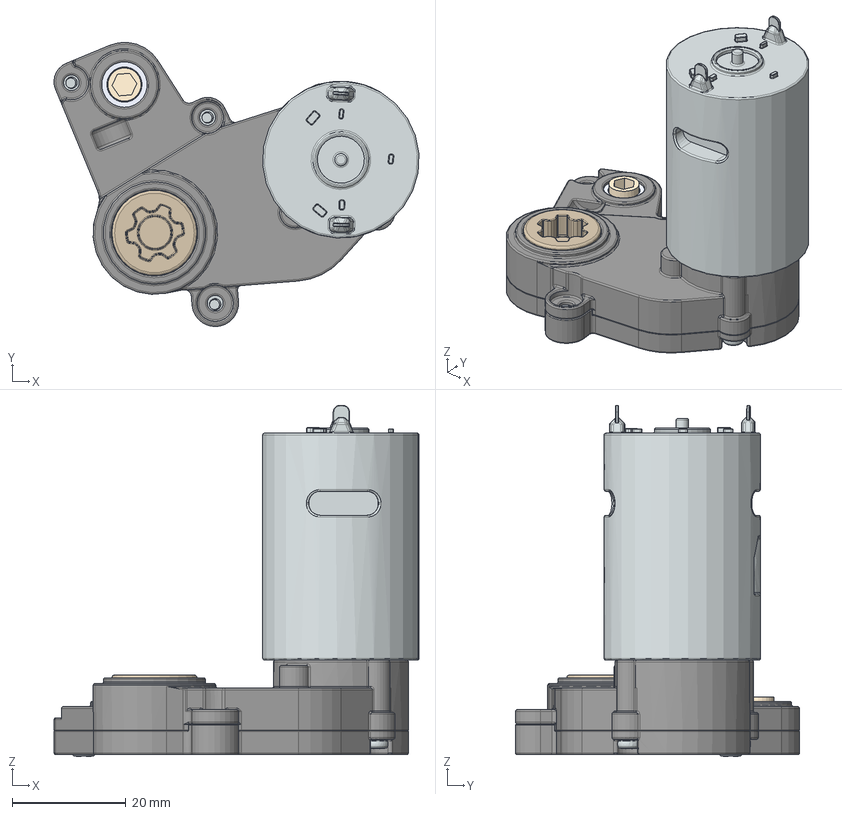
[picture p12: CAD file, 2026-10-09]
designs/one/stock/STEP/03-01 Motor_Gearbox.step
64.1 x 49.9 x 61.8 mm
M2 x 9
RS-385PH-2466 DC Motor
OOM-M03-01-07
shaft3-030102
shaft2-030102
shaft1-030102
JSM-1416-05_stp
bearing_mr106zz_0_x_t_stp
OOM-M03-02-05_step
OOM-M03-01-06_STANDARD_GEAR_step6228
OOM-M03-01-04_step73038
OOM-M03-01-05_step
AMC030604 Metric Plain Oilite Bush
shaft-030101
OOM-M03-01-03_step101114

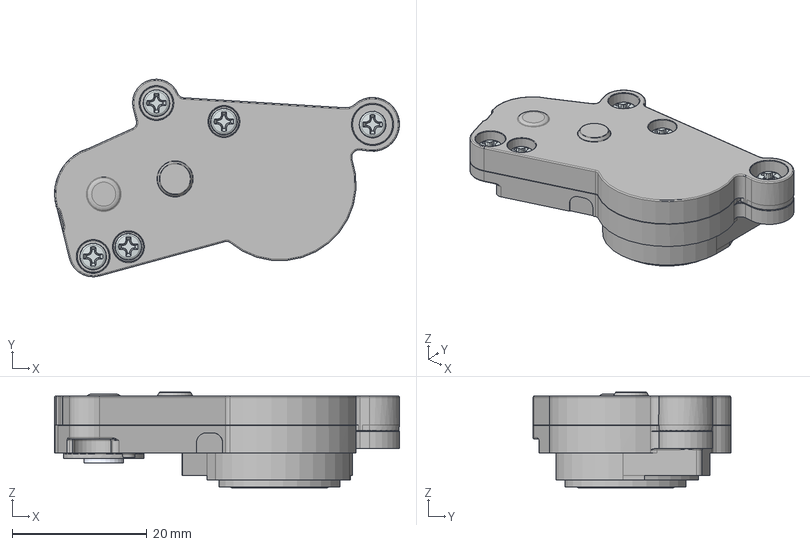
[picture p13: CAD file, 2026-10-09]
designs/one/stock/STEP/03-02 Red_Brush_Gearbox_step.step
51.3 x 29.4 x 14.2 mm
JSM-1416-05_stp
shaft-3_stp
bronze-sae841-sleeve-bearing-AM-306-5
shaft-1
M2 x 5
OOM-M03-02-05_step
OOM-M03-02-04
OOM-M03-02-03_step

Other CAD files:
designs/one/stock/03-01 Motor_Gearbox.f3d
designs/one/stock/03-02 Red_Brush_Gearbox_step.f3d
designs/one/stock/C01 Top Assembly.f3d
designs/one/stock/C01_2_base_snapshot.f3d
designs/one/stock/OOM-M02-Assembly.f3d
designs/one/stock/Top_Assembly_081426a.f3z

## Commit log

2026-09-27 Add MSDG fan, HEPA filter
2026-09-30 Fixed cliff sensor STEP
2026-10-02 Cliff sensor fix
2026-10-03 Fixed cliff sensor
2026-10-07 Dreame hex-mount side brush
2026-10-09 Reorganize into designs/<product>/<variant>
    fuison360/ (misspelled) becomes designs/one/stock/: one folder per
    product, one subfolder per variant, so a mod that touches several parts
    (a top plate for a cat to ride, say) can live as a whole design next to
    the stock one. AI-generated experiments go under designs/one/agentic/.
    READMEs explain the layout and how to add a variant; the root README
    gains a short layout section. Also fixes docs/SPEC.md linking
    docs/dock_teardown_x20.pdf from inside docs/.
    [03-01 Motor_Gearbox.f3d, 03-01 Motor_Gearbox.step, 03-02 Red_Brush_Gearbox_step.f3d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]
2026-10-09 Add July 2026 agentic CAD experiment (RV02 STEP + report)
    An LLM-driven multi-agent CAD pipeline (Claude Code with Claude Fable 5,
    build123d) turned the July spec and component STEPs into a closed,
    3D-printable robot vacuum. Kept as a reference, not the design: the
    README lists what worked and what human review found wrong.
    Re-landed from #2 into the new designs/one/agentic/ layout. The report's
    client name was shortened to "Ilia O." before publishing.
    [device_full.step]
2026-10-26 Main brush prototype works
2026-11-01 Drive wheels proto brought up
2026-11-06 Bumper sensors

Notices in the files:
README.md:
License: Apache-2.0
